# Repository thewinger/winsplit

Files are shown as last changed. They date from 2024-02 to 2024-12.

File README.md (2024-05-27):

# Winsplit

Inspired by the Boardrun Bizarre and Red herring. I wanted to be able to use a normal keyset, so no full ortho, but split.

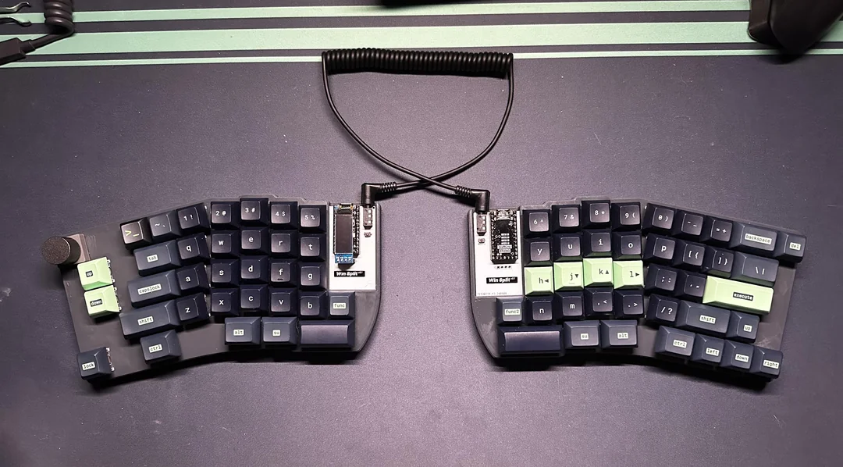
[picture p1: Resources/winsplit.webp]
Keyboard


## Disclaimer

This is my first designed keyboard from the grounds up.
I'm not responsible for any damage caused by using this keyboard or any production of this keyboard that doesn't work.

## Bill of materials

To be bought separately:

- 2x [RP2040 Pro Micro](https://es.aliexpress.com/item/1005006130019224.html).
- 70x pin headers
- 1x [Skyloong Rotary Encoder](https://es.aliexpress.com/item/1005005189266585.html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).
- 2x [TRRS Connector](https://es.aliexpress.com/item/33029465106.html).
- 2x [SMD Buttons](https://es.aliexpress.com/item/33013562004.html).
- 2x 128x32 [OLED panels](https://es.aliexpress.com/item/1005005973981064.html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).
- 73x [Kailh hotswap sockets](https://es.aliexpress.com/item/1005004290562374.html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).
- 73x [SK6812MINI-E leds](https://es.aliexpress.com/item/1005004908622116.html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).
- 4x 2u Stabilizers.
- 16x M2 6mm screws.

Diodes, capacitors, resistors and other small parts are to be soldered directly by JLCPCB. References in KiCad files.

## TODO

- [ ] **Rotate 180º right-side OLED connector.** Right now is not usable.
- [ ] **Rotary encoder.** As of now, it either works as a button when a normal switch is installed or as an encoder without button when the HS Skyloong encoder is installed.
- [ ] **Make screw holes in PCB 4mm instead of 2.2mm.** So they are passthrougth and bottom plate can be directly screwed to top plate, like lily58 or Corne keyboards.

## Notes

- Function keys (Right of B and left of N) are hard to reach.

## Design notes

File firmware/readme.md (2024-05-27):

# winsplit

winsplit

*A short description of the keyboard/project*

* Keyboard Maintainer: [thewinger](https://github.com/thewinger)
* Hardware Supported: *The PCBs, controllers supported*
* Hardware Availability: *Links to where you can find this hardware*

Make example for this keyboard (after setting up your build environment):

    make winsplit:default

Flashing example for this keyboard:

    make winsplit:default:flash

See the [build environment setup](https://docs.qmk.fm/#/getting_started_build_tools) and the [make instructions](https://docs.qmk.fm/#/getting_started_make_guide) for more information. Brand new to QMK? Start with our [Complete Newbs Guide](https://docs.qmk.fm/#/newbs).

## Bootloader

Enter the bootloader in 3 ways:

* **Bootmagic reset**: Hold down the key at (0,0) in the matrix (usually the top left key or Escape) and plug in the keyboard
* **Physical reset button**: Briefly press the button on the back of the PCB - some may have pads you must short instead
* **Keycode in layout**: Press the key mapped to `QK_BOOT` if it is available

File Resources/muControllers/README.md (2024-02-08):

# KiCAD Microcontroller symbols
Project boards for projects

(copyright and licensing info at bottom of this file)

This repository contains symbol libraries for use with KiCAD. These symbol
libraries are a selection of popular or notable microcontrollers. The goal is
to proveide the open source hardware community with tools to more easily create
new and interesting PCB projects without needing to redefine the wheel evey
single time.

## Supported boards
* Teensy
    * Teensy LC
    * Teensy 4.0
* RP2040
    * Raspberry Pi Pico
    * KB2040
* Others
    * Arduino Pro Micro
    * Adafruit Itsy Bitsy
    * CircuitBrains Deluxe
    * WeAct BlackPill

## Upcoming work
Provide footprints for all symbols

## Copyright and License
(c) Travis Rigg 2022, made available under the terms of the GNU LGPL 3.0



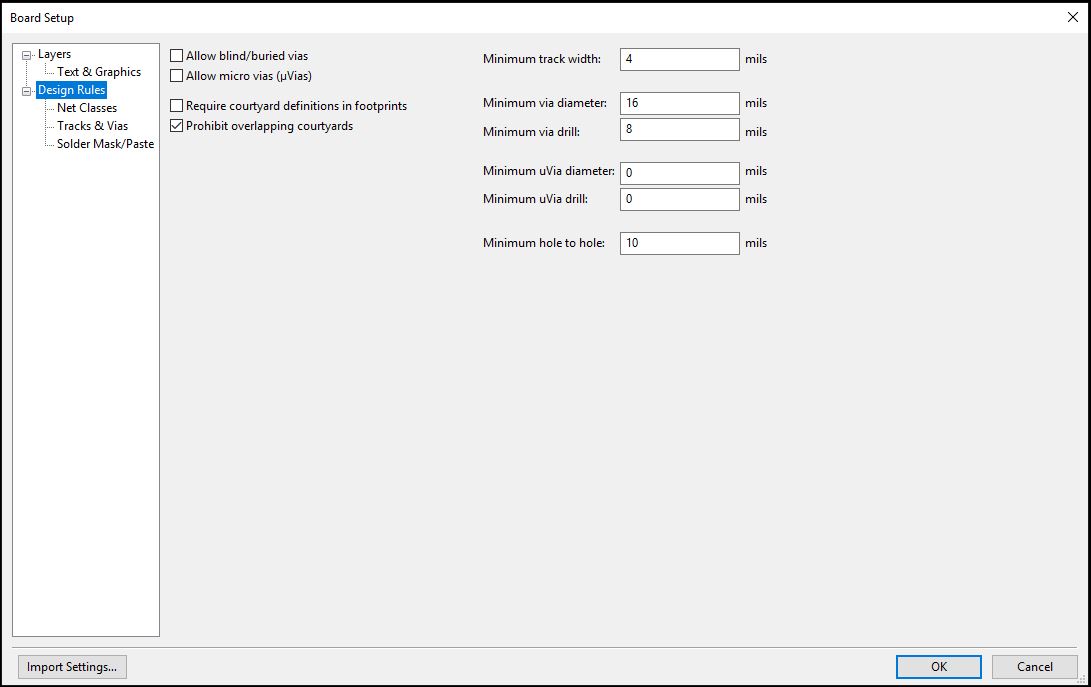
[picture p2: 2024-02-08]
Resources/kicad_templates-master/Sierra 10 layer Board/meta/Images/Design Rules.JPG

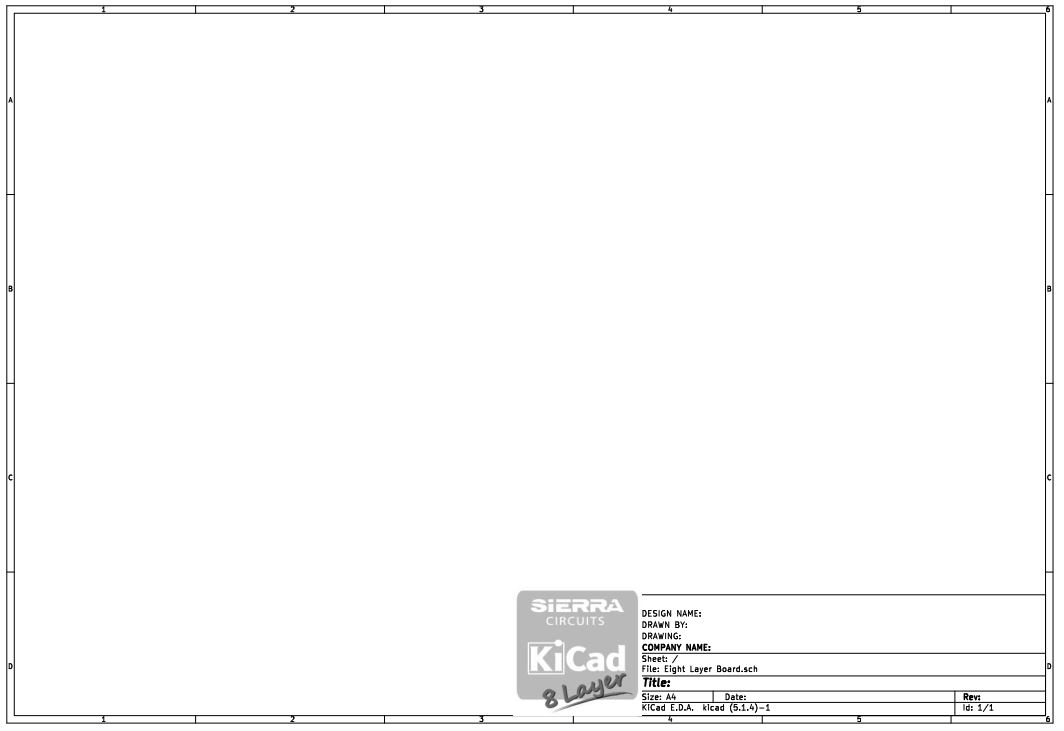
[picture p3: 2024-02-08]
Resources/kicad_templates-master/Sierra 8 layer Board/meta/Images/schematic.jpg

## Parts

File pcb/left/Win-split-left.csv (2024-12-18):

Id | Designator | Footprint | Quantity | Designation | Supplier and ref
1 | H1,H5,H6,H2,H8,H7,H3,H4 | HOLE_M2 | 8 | MountingHole_Pad
2 | S33,S23 | STAB_MX_P_2u | 2 | MX_stab
3 | J1 | PinHeader_1x04_P2.54mm_Vertical | 1 | Conn_01x04_Socket
4 | Reset1 | SW_SPST_B3U-1000P | 1 | Switch
5 | TRRS1 | TRRS_PJ-320A | 1 | TRRS
6 | U1 | RP2040_ProMicro_USBup | 1 | RP2040_ProMicro
7 | LED19,LED1,LED20,LED29,LED2,LED4,LED22,LED8,LED33,LED31,LED7,LED32,LED17,LED18,LED30,LED5,LED6,LED16,LED21,LED3 | LED_MX_6028R | 20 | MX_SK6812MINI-E
8 | D7,D19,D18,D20,D11,D15,D21,D29,D9,D12,D2,D23,D10,D5,D26,D31,D22,D34,D4,D3,D16,D8,D27,D13,D24,D6,D28,D1,D17,D14,D33,D30,D32,D25 | Diode_SOD-123 | 34 | Diode
9 | LED15,LED23,LED34,LED28,LED10,LED24,LED11,LED13,LED12,LED14,LED25,LED27,LED9,LED26 | LED_MX_6028R-ROT | 14 | MX_SK6812MINI-E
10 | MX33,MX8,MX6,MX14,MX11,MX5,MX17,MX27,MX3,MX20,MX10,MX28,MX13,MX22,MX21,MX15,MX29,MX26,MX12,MX25,MX1,MX19,MX4,MX2,MX24,MX34,MX23,MX7,MX18 | SW_MX_HS_CPG151101S11_1u | 29 | MX_SW_HS
11 | C5,C24,C28,C33,C34,C16,C1,C13,C29,C31,C32,C6,C30,C8,C14,C21,C4,C17,C20,C22,C3,C25,C9,C23,C11,C2,C12,C27,C15,C26,C10,C7,C19,C18,C100 | C_0402_1005Metric | 35 | 100nF
12 | MX32,MX30,MX31 | SW_MX_HS_CPG151101S11_1.25u | 3 | MX_SW_HS
13 | R2 | R_0805_2012Metric | 1 | 4.7K
14 | U3 | SOT-23-5 | 1 | 74AHCT1G125
15 | MX16 | SW_MX_HS_CPG151101S11_1.75u | 1 | MX_SW_HS
16 | Q1 | SOT-23 | 1 | Q_PMOS_GSD
17 | R1 | R_0805_2012Metric | 1 | 1K
18 | MX9 | SW_MX_HS_CPG151101S11_1.5u | 1 | MX_SW_HS

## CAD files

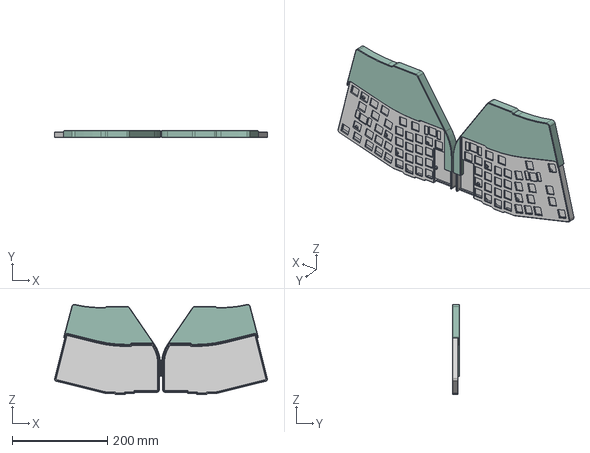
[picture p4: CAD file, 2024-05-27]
3D/Case winsplit.step
447.6 x 15.0 x 189.4 mm

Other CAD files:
3D/Case winsplit.3mf

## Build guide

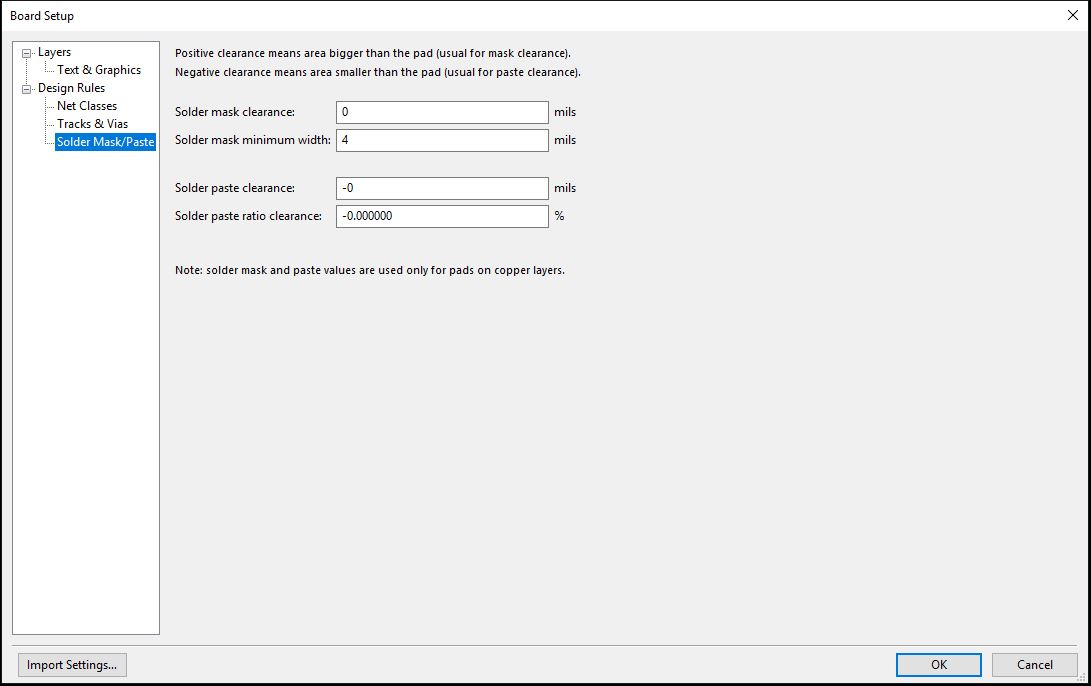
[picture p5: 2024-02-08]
Resources/kicad_templates-master/Sierra 2 layer Board/meta/Images/Solder Mask & Paste.JPG

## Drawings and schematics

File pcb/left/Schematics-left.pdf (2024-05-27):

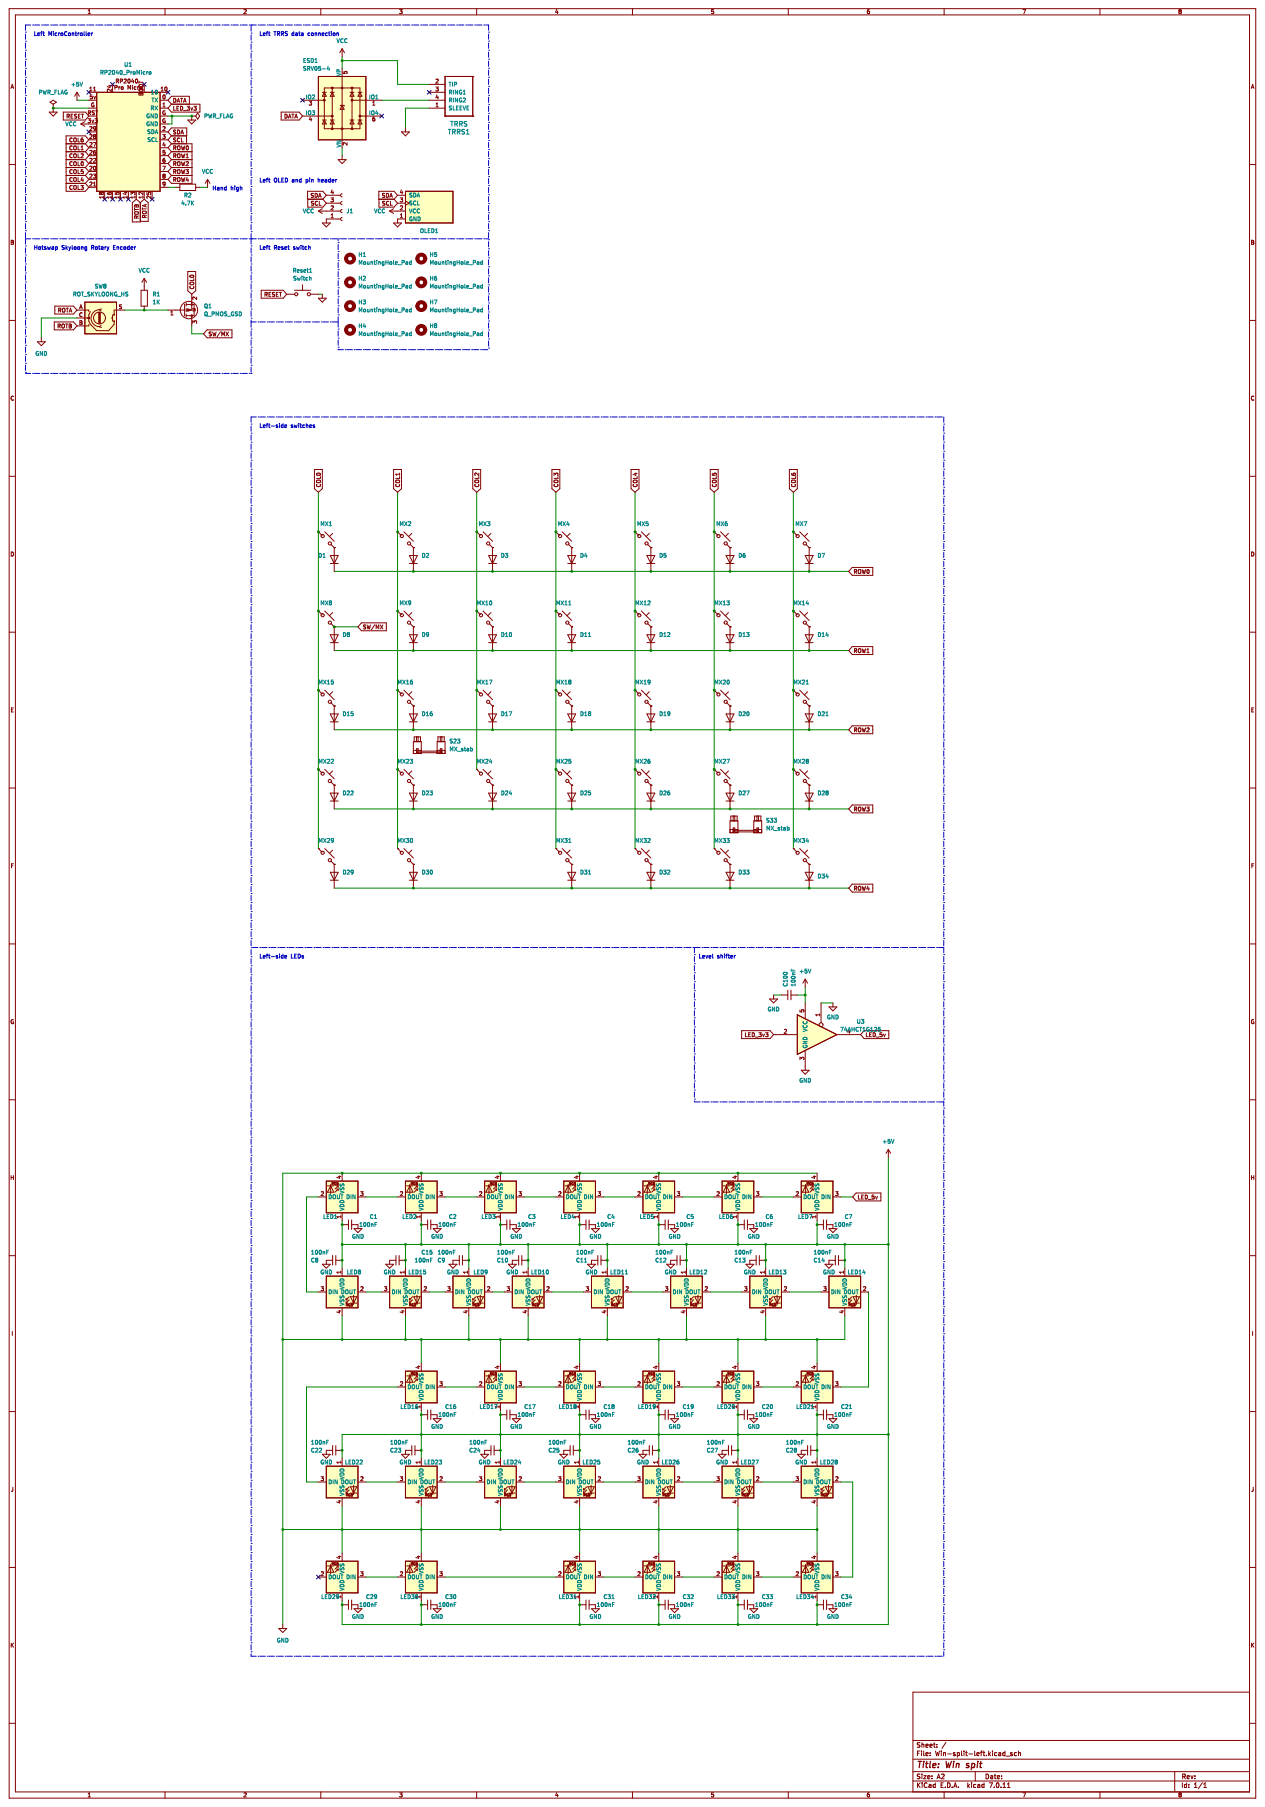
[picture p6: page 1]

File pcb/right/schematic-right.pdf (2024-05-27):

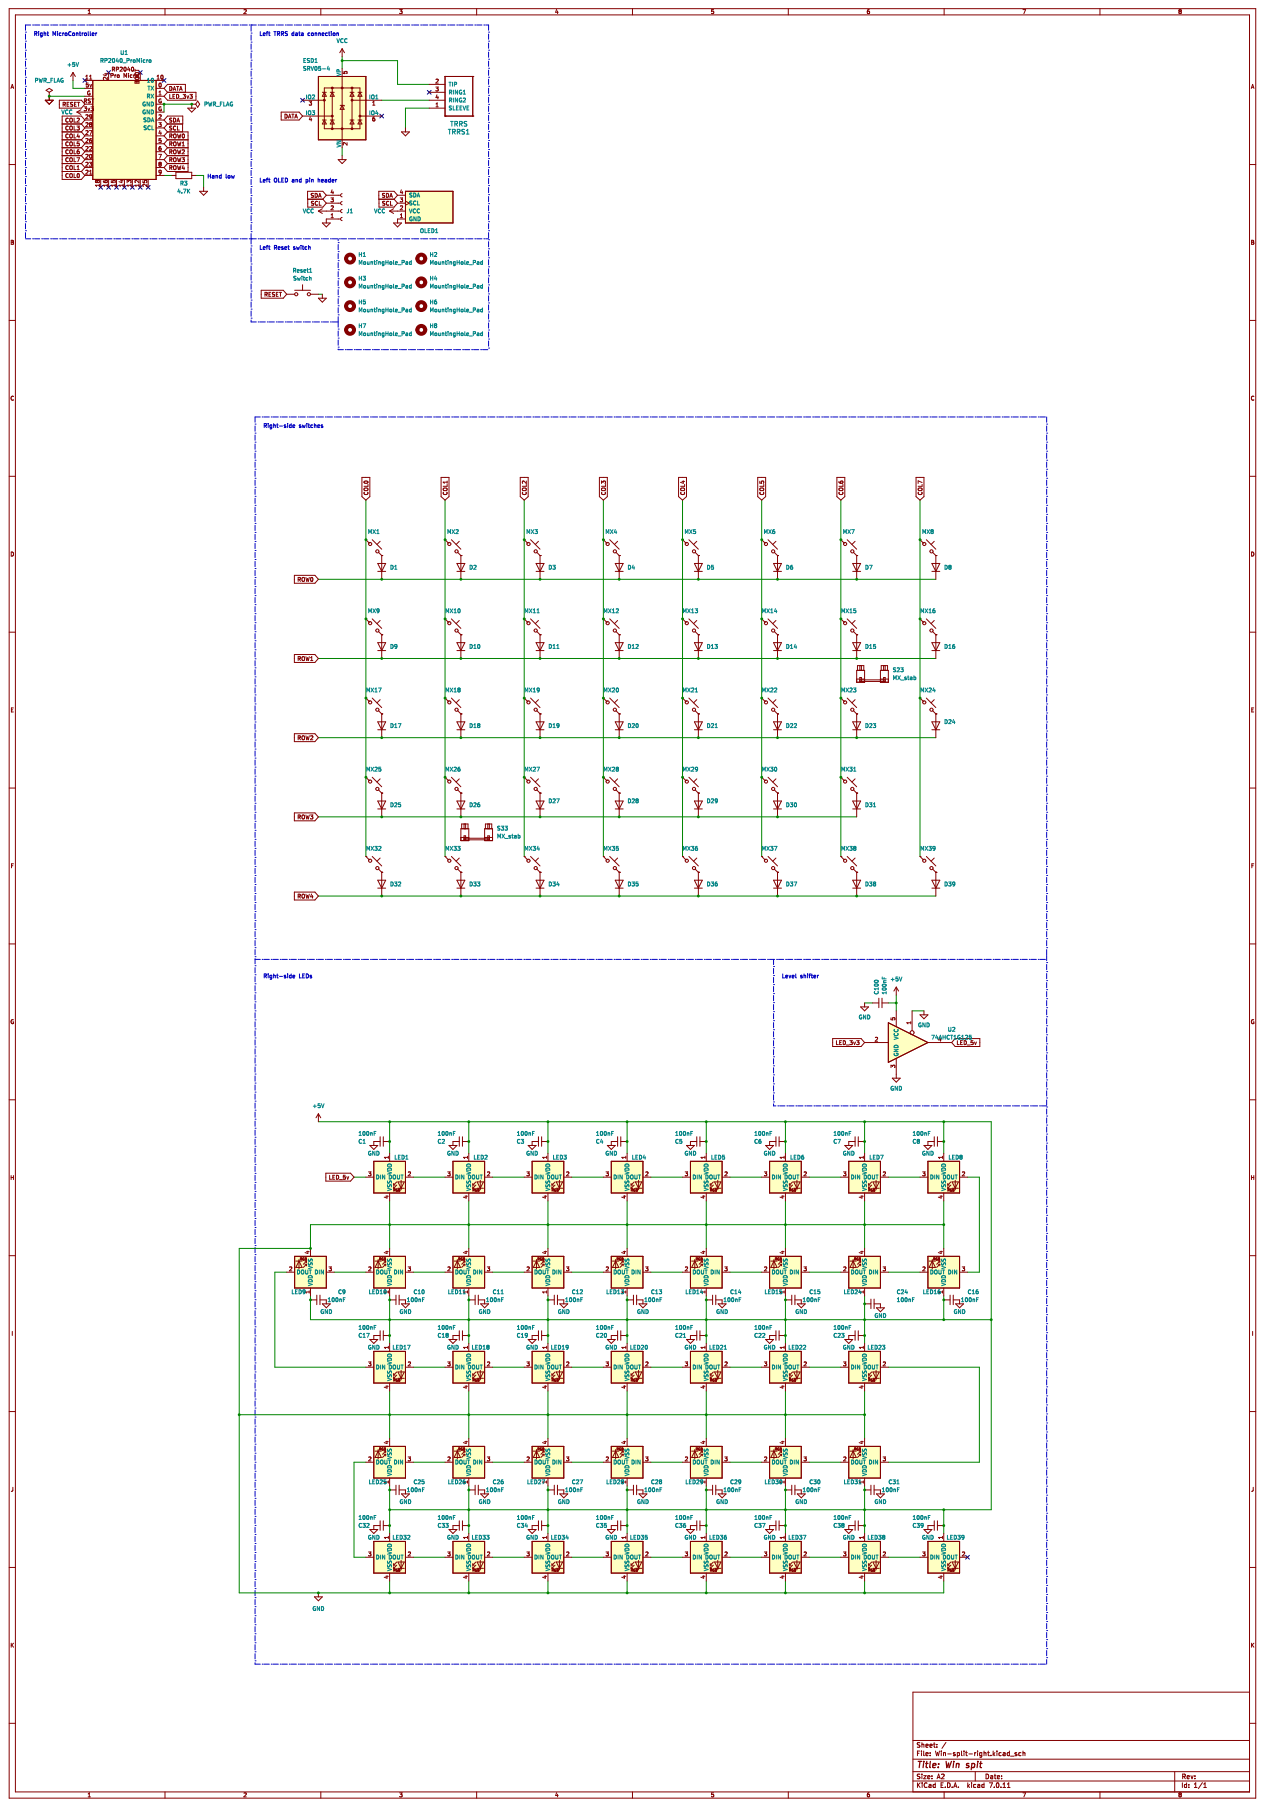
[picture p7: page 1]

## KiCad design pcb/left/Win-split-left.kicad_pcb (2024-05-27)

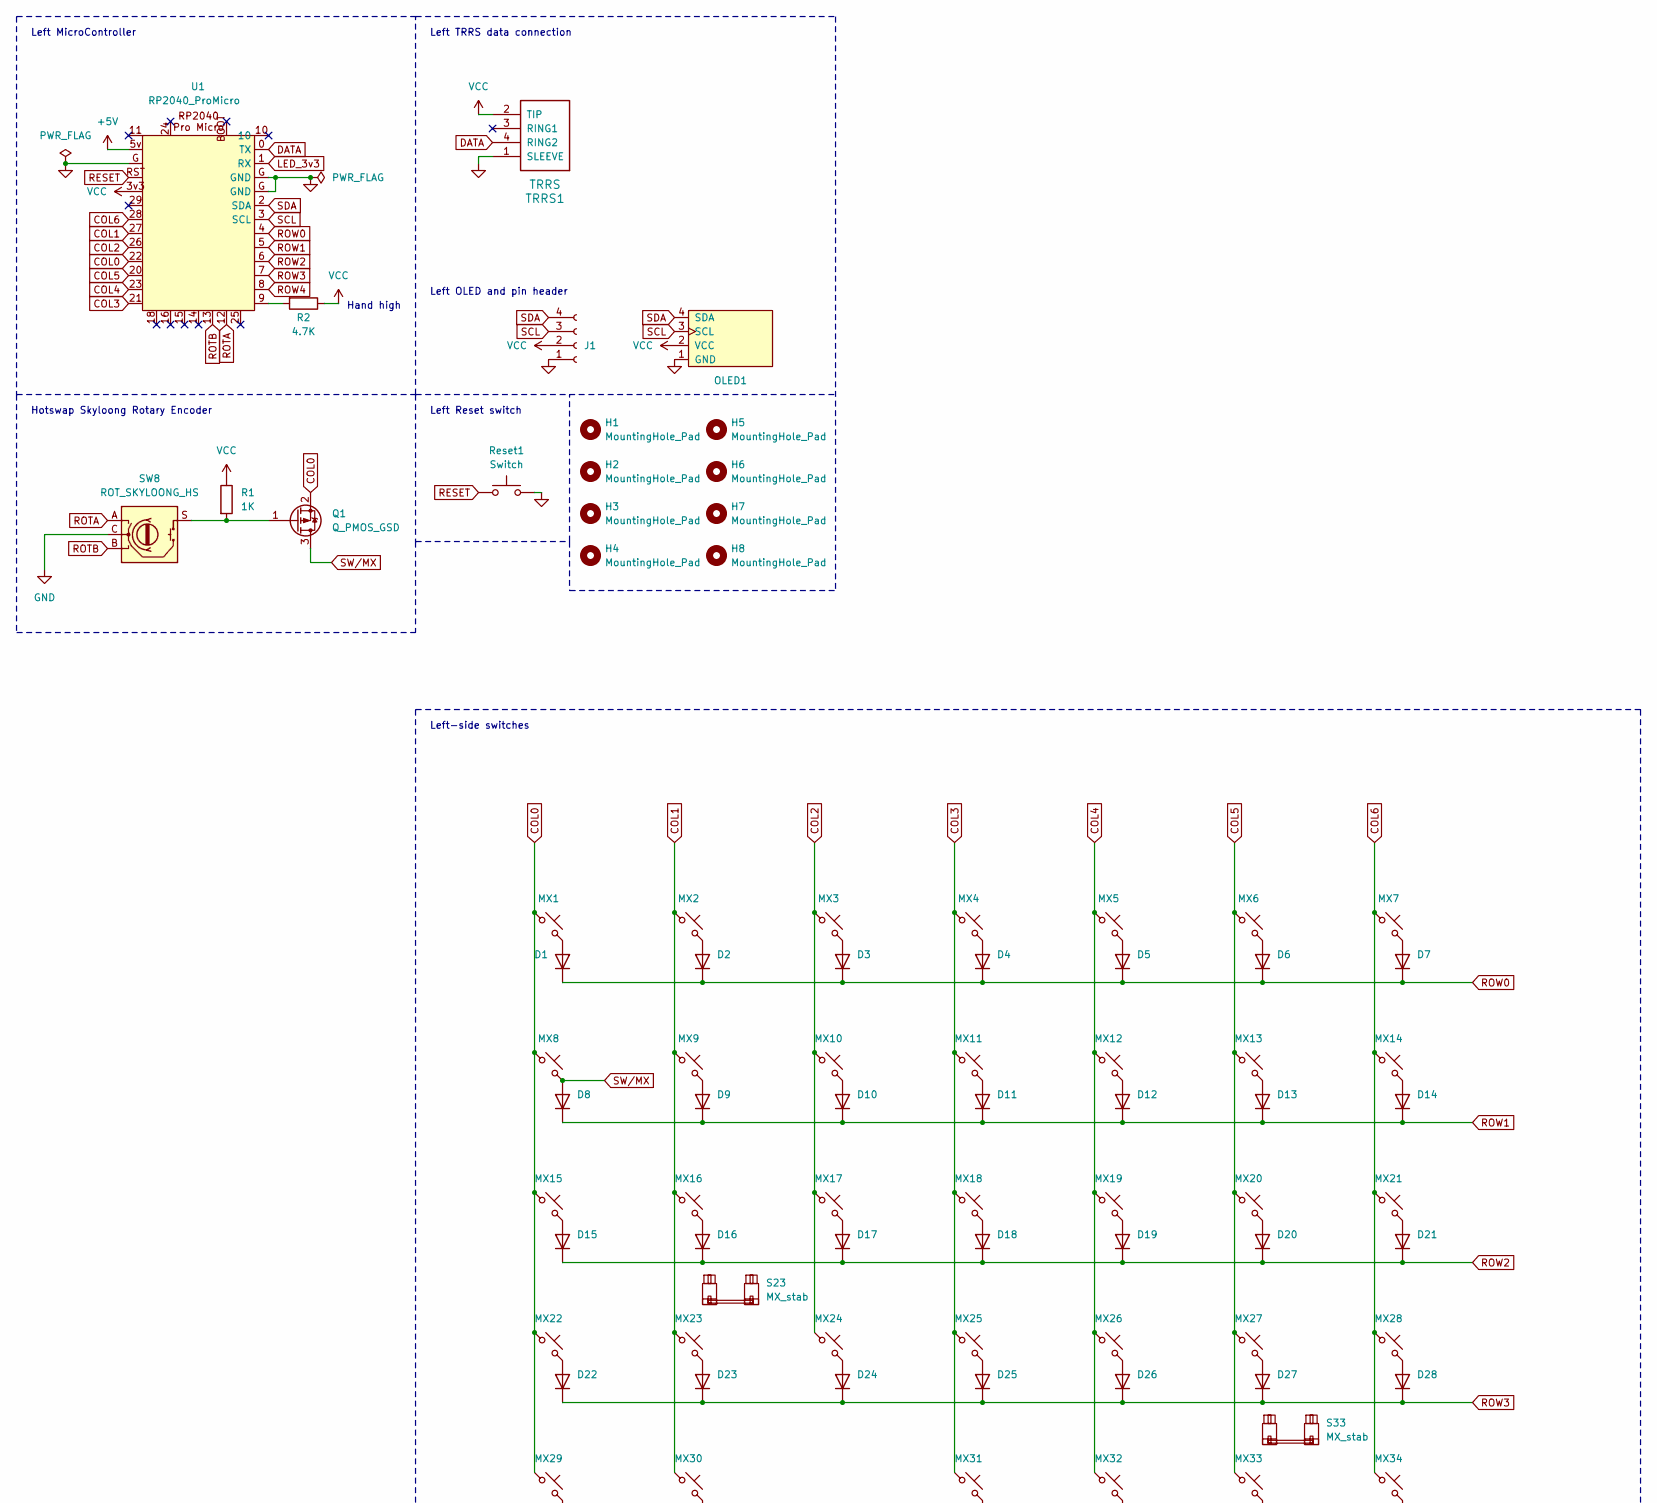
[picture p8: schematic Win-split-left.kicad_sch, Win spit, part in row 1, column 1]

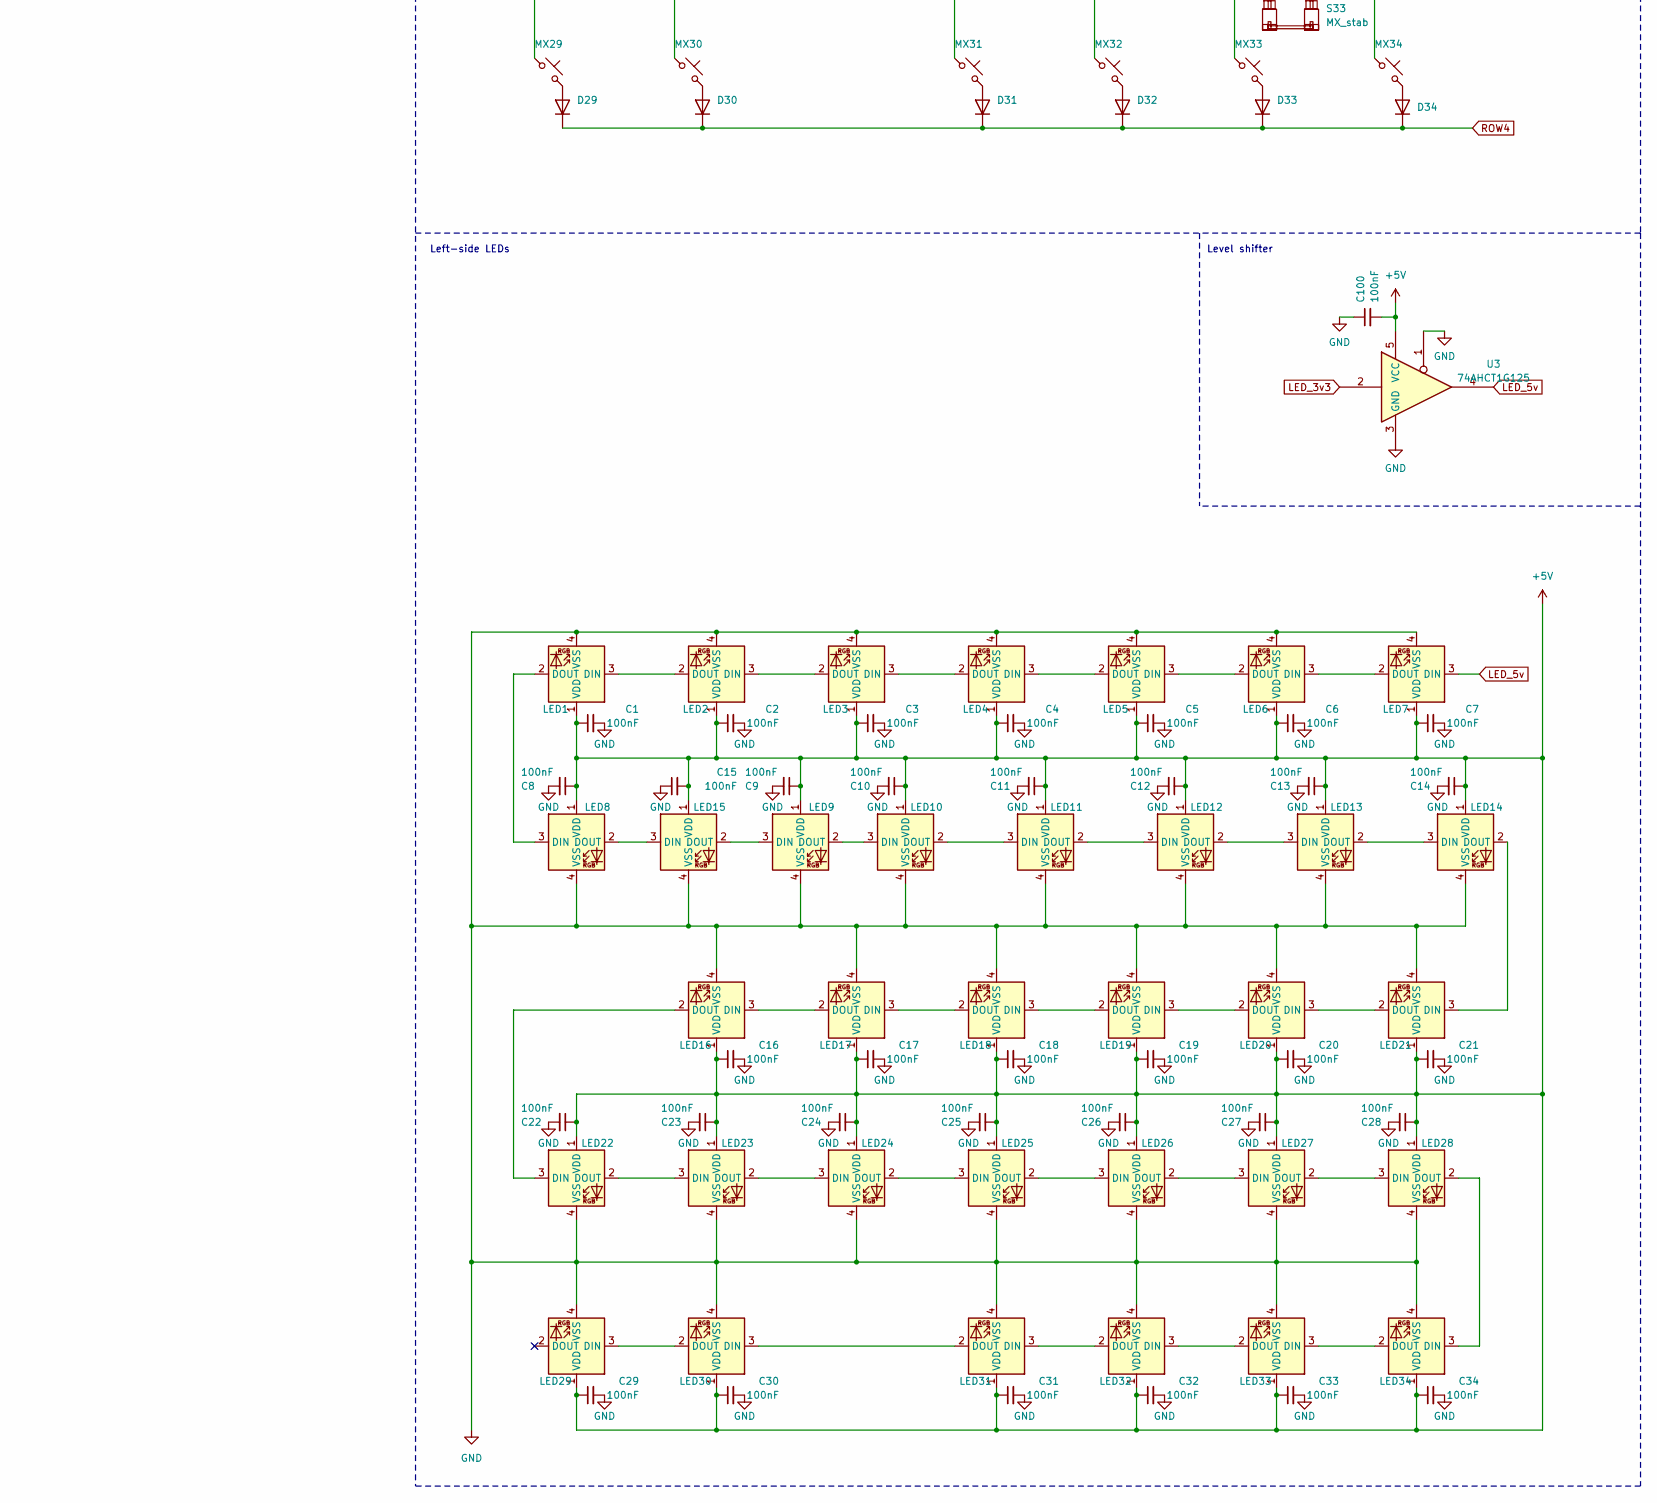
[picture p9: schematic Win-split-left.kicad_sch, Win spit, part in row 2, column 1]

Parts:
C1, C2, C3, C4, C5, C6, C7, C8, C9, C10, C11, C12, C13, C14, C15, C16, C17, C18, C19, C20, C21, C22, C23, C24, C25, C26, C27, C28, C29, C30, C31, C32, C33, C34, C100: 100nF; C_0402_1005Metric; LCSC C1525
D1, D2, D3, D4, D5, D6, D7, D8, D9, D10, D11, D12, D13, D14, D15, D16, D17, D18, D19, D20, D21, D22, D23, D24, D25, D26, D27, D28, D29, D30, D31, D32, D33, D34: Diode; Diode_SOD-123; LCSC C81598
H1, H2, H3, H4, H5, H6, H7, H8: MountingHole_Pad; HOLE_M2
J1: Conn_01x04_Socket; PinHeader_1x04_P2.54mm_Vertical
LED1, LED2, LED3, LED4, LED5, LED6, LED7, LED8, LED16, LED17, LED18, LED19, LED20, LED21, LED22, LED29, LED30, LED31, LED32, LED33: MX_SK6812MINI-E; LED_MX_6028R
LED9, LED10, LED11, LED12, LED13, LED14, LED15, LED23, LED24, LED25, LED26, LED27, LED28, LED34: MX_SK6812MINI-E; LED_MX_6028R-ROT
MX1, MX2, MX3, MX4, MX5, MX6, MX7, MX8, MX10, MX11, MX12, MX13, MX14, MX15, MX17, MX18, MX19, MX20, MX21, MX22, MX23, MX24, MX25, MX26, MX27, MX28, MX29, MX33, MX34: MX_SW_HS; SW_MX_HS_CPG151101S11_1u
MX9: MX_SW_HS; SW_MX_HS_CPG151101S11_1.5u
MX16: MX_SW_HS; SW_MX_HS_CPG151101S11_1.75u
MX30, MX31, MX32: MX_SW_HS; SW_MX_HS_CPG151101S11_1.25u
OLED1: OLED_128x32
Q1: Q_PMOS_GSD; SOT-23; LCSC C133325
R1: 1K; R_0805_2012Metric; LCSC C17513
R2: 4.7K; R_0805_2012Metric; LCSC C17673
Reset1: Switch; SW_SPST_B3U-1000P; LCSC C231329
S23, S33: MX_stab; STAB_MX_P_2u
SW8: ROT_SKYLOONG_HS; ROT_SKYLOONG_HS-Switch
TRRS1: TRRS; TRRS_PJ-320A
U1: RP2040_ProMicro; RP2040_ProMicro_USBup
U3: 74AHCT1G125; SOT-23-5; LCSC C7484

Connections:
+5V: C1.1, C2.1, C3.1, C4.1, C5.1, C6.1, C7.1, C8.1, C9.1, C10.1, C11.1, C12.1, C13.1, C14.1, C15.2, C16.1, C17.1, C18.1, C19.1, C20.1, C21.1, C22.1, C23.1, C24.1, C25.1, C26.1, C27.1, C28.1, C29.1, C30.1, C31.1, C32.1, C33.1, C34.1, C100.2, LED1.1 (VDD), LED2.1 (VDD), LED3.1 (VDD), LED4.1 (VDD), LED5.1 (VDD), LED6.1 (VDD), LED7.1 (VDD), LED8.1 (VDD), LED9.1 (VDD), LED10.1 (VDD), LED11.1 (VDD), LED12.1 (VDD), LED13.1 (VDD), LED14.1 (VDD), LED15.1 (VDD), LED16.1 (VDD), LED17.1 (VDD), LED18.1 (VDD), LED19.1 (VDD), LED20.1 (VDD), LED21.1 (VDD), LED22.1 (VDD), LED23.1 (VDD), LED24.1 (VDD), LED25.1 (VDD), LED26.1 (VDD), LED27.1 (VDD), LED28.1 (VDD), LED29.1 (VDD), LED30.1 (VDD), LED31.1 (VDD), LED32.1 (VDD), LED33.1 (VDD), LED34.1 (VDD), U1.5v, U3.5 (VCC)
COL0: MX1.1, MX8.1, MX15.1, MX22.1, MX29.1, Q1.2 (S), U1.22
COL1: MX2.1, MX9.1, MX16.1, MX23.1, MX30.1, U1.27
COL2: MX3.1, MX10.1, MX17.1, MX24.1, U1.26
COL3: MX4.1, MX11.1, MX18.1, MX25.1, MX31.1, U1.21
COL4: MX5.1, MX12.1, MX19.1, MX26.1, MX32.1, U1.23
COL5: MX6.1, MX13.1, MX20.1, MX27.1, MX33.1, U1.20
COL6: MX7.1, MX14.1, MX21.1, MX28.1, MX34.1, U1.28
DATA: TRRS1.4 (RING2), U1.0 (TX)
GND: C1.2, C2.2, C3.2, C4.2, C5.2, C6.2, C7.2, C8.2, C9.2, C10.2, C11.2, C12.2, C13.2, C14.2, C15.1, C16.2, C17.2, C18.2, C19.2, C20.2, C21.2, C22.2, C23.2, C24.2, C25.2, C26.2, C27.2, C28.2, C29.2, C30.2, C31.2, C32.2, C33.2, C34.2, C100.1, J1.1, LED1.4 (VSS), LED2.4 (VSS), LED3.4 (VSS), LED4.4 (VSS), LED5.4 (VSS), LED6.4 (VSS), LED7.4 (VSS), LED8.4 (VSS), LED9.4 (VSS), LED10.4 (VSS), LED11.4 (VSS), LED12.4 (VSS), LED13.4 (VSS), LED14.4 (VSS), LED15.4 (VSS), LED16.4 (VSS), LED17.4 (VSS), LED18.4 (VSS), LED19.4 (VSS), LED20.4 (VSS), LED21.4 (VSS), LED22.4 (VSS), LED23.4 (VSS), LED24.4 (VSS), LED25.4 (VSS), LED26.4 (VSS), LED27.4 (VSS), LED28.4 (VSS), LED29.4 (VSS), LED30.4 (VSS), LED31.4 (VSS), LED32.4 (VSS), LED33.4 (VSS), LED34.4 (VSS), OLED1.1 (GND), Reset1.2, SW8.C, TRRS1.1 (SLEEVE), U1.G (GND), U3.1, U3.3 (GND)
LED_3v3: U1.1 (RX), U3.2
LED_5v: LED7.3 (DIN), U3.4
unnamed: D1.2 (A), MX1.2
unnamed: D2.2 (A), MX2.2
unnamed: D3.2 (A), MX3.2
unnamed: D4.2 (A), MX4.2
unnamed: D5.2 (A), MX5.2
unnamed: D6.2 (A), MX6.2
unnamed: D7.2 (A), MX7.2
unnamed: D9.2 (A), MX9.2
unnamed: D10.2 (A), MX10.2
unnamed: D11.2 (A), MX11.2
unnamed: D12.2 (A), MX12.2
unnamed: D13.2 (A), MX13.2
unnamed: D14.2 (A), MX14.2
unnamed: D15.2 (A), MX15.2
unnamed: D16.2 (A), MX16.2
unnamed: D17.2 (A), MX17.2
unnamed: D18.2 (A), MX18.2
unnamed: D19.2 (A), MX19.2
unnamed: D20.2 (A), MX20.2
unnamed: D21.2 (A), MX21.2
unnamed: D22.2 (A), MX22.2
unnamed: D23.2 (A), MX23.2
unnamed: D24.2 (A), MX24.2
unnamed: D25.2 (A), MX25.2
unnamed: D26.2 (A), MX26.2
unnamed: D27.2 (A), MX27.2
unnamed: D28.2 (A), MX28.2
unnamed: D29.2 (A), MX29.2
unnamed: D30.2 (A), MX30.2
unnamed: D31.2 (A), MX31.2
unnamed: D32.2 (A), MX32.2
unnamed: D33.2 (A), MX33.2
unnamed: D34.2 (A), MX34.2
unnamed: LED1.3 (DIN), LED2.2 (DOUT)
unnamed: LED1.2 (DOUT), LED8.3 (DIN)
unnamed: LED2.3 (DIN), LED3.2 (DOUT)
unnamed: LED3.3 (DIN), LED4.2 (DOUT)
unnamed: LED4.3 (DIN), LED5.2 (DOUT)
unnamed: LED5.3 (DIN), LED6.2 (DOUT)
unnamed: LED6.3 (DIN), LED7.2 (DOUT)
unnamed: LED9.2 (DOUT), LED10.3 (DIN)
unnamed: LED10.2 (DOUT), LED11.3 (DIN)
unnamed: LED11.2 (DOUT), LED12.3 (DIN)
unnamed: LED12.2 (DOUT), LED13.3 (DIN)
unnamed: LED13.2 (DOUT), LED14.3 (DIN)
unnamed: LED14.2 (DOUT), LED21.3 (DIN)
unnamed: LED8.2 (DOUT), LED15.3 (DIN)
unnamed: LED9.3 (DIN), LED15.2 (DOUT)
unnamed: LED16.3 (DIN), LED17.2 (DOUT)
unnamed: LED16.2 (DOUT), LED22.3 (DIN)
unnamed: LED17.3 (DIN), LED18.2 (DOUT)
unnamed: LED18.3 (DIN), LED19.2 (DOUT)
unnamed: LED19.3 (DIN), LED20.2 (DOUT)
unnamed: LED20.3 (DIN), LED21.2 (DOUT)
unnamed: LED22.2 (DOUT), LED23.3 (DIN)
unnamed: LED23.2 (DOUT), LED24.3 (DIN)
unnamed: LED24.2 (DOUT), LED25.3 (DIN)
unnamed: LED25.2 (DOUT), LED26.3 (DIN)
unnamed: LED26.2 (DOUT), LED27.3 (DIN)
unnamed: LED27.2 (DOUT), LED28.3 (DIN)
unnamed: LED28.2 (DOUT), LED34.3 (DIN)
unnamed: LED29.3 (DIN), LED30.2 (DOUT)
unnamed: LED30.3 (DIN), LED31.2 (DOUT)
unnamed: LED31.3 (DIN), LED32.2 (DOUT)
unnamed: LED32.3 (DIN), LED33.2 (DOUT)
unnamed: LED33.3 (DIN), LED34.2 (DOUT)
unnamed: Q1.1 (G), R1.2, SW8.S
unnamed: R2.2, U1.9
RESET: Reset1.1, U1.RST
ROTA: SW8.A, U1.12
ROTB: SW8.B, U1.13
ROW0: D1.1 (K), D2.1 (K), D3.1 (K), D4.1 (K), D5.1 (K), D6.1 (K), D7.1 (K), U1.4
ROW1: D8.1 (K), D9.1 (K), D10.1 (K), D11.1 (K), D12.1 (K), D13.1 (K), D14.1 (K), U1.5
ROW2: D15.1 (K), D16.1 (K), D17.1 (K), D18.1 (K), D19.1 (K), D20.1 (K), D21.1 (K), U1.6
ROW3: D22.1 (K), D23.1 (K), D24.1 (K), D25.1 (K), D26.1 (K), D27.1 (K), D28.1 (K), U1.7
ROW4: D29.1 (K), D30.1 (K), D31.1 (K), D32.1 (K), D33.1 (K), D34.1 (K), U1.8
SCL: J1.3, OLED1.3 (SCL), U1.3 (SCL)
SDA: J1.4, OLED1.4 (SDA), U1.2 (SDA)
SW/MX: D8.2 (A), MX8.2, Q1.3 (D)
VCC: J1.2, OLED1.2 (VCC), R1.1, R2.1, TRRS1.2 (TIP), U1.3v3

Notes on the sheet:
Left-side switches
Left MicroController
Left Reset switch
Left OLED and pin header
Level shifter
Left-side LEDs
Hand high
Left TRRS data connection
Hotswap Skyloong Rotary Encoder

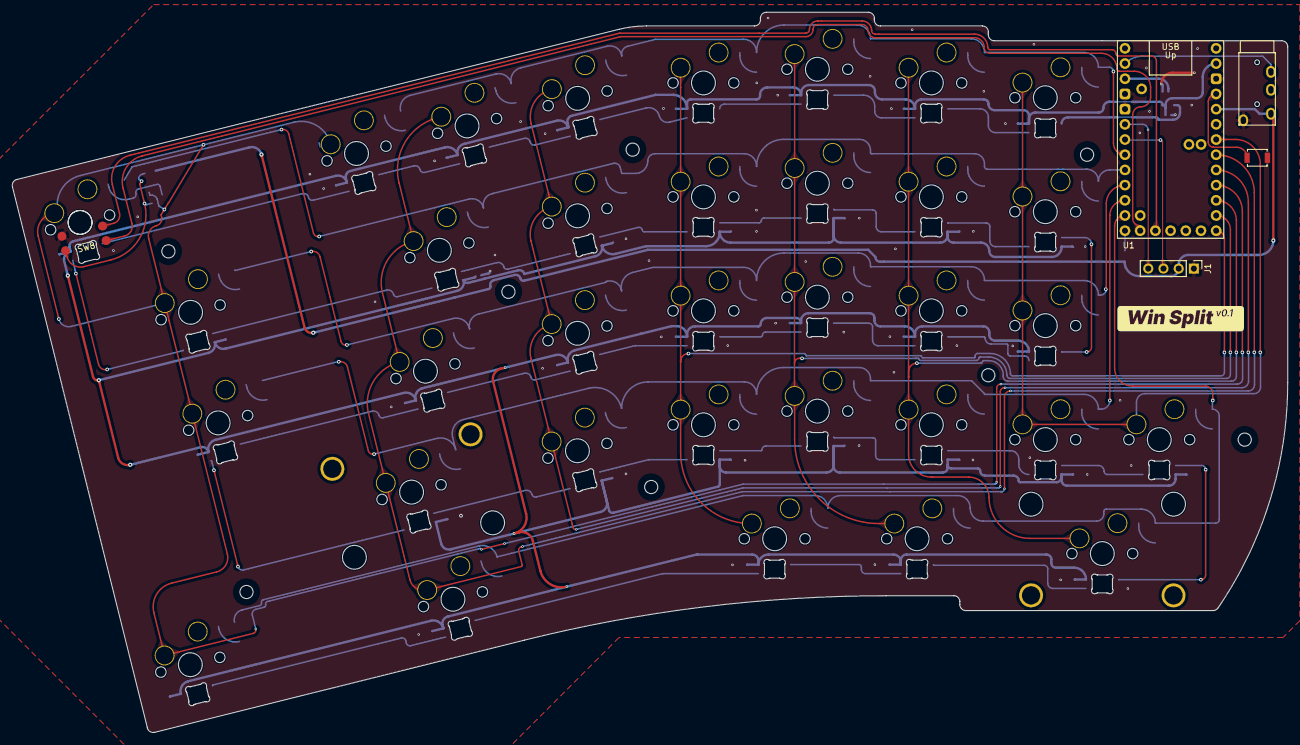
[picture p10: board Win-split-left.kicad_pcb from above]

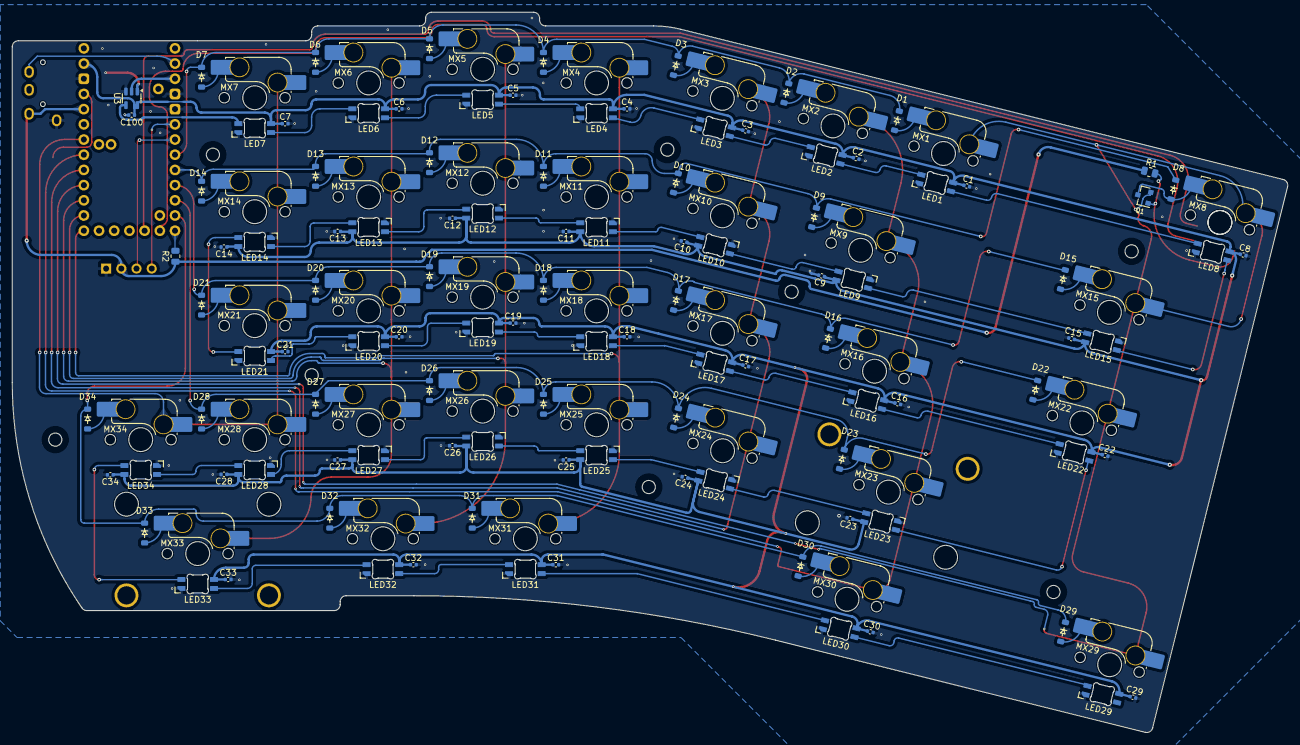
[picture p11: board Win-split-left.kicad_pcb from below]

Board: 2 copper layers, 213.2 x 120.4 mm, 156 parts (141 on the bottom side), 92 nets.

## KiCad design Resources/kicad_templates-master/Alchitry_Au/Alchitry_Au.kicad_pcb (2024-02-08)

Board: 2 copper layers, 8 parts (0 on the bottom side), 3 nets, no tracks yet.

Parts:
B1, B2, B3, B4: Alchitry_Shield; Alchitry_Conn
H1, H2, H3, H4: MountingHole; 2m2ThroughHole

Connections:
+3V3: B1.B7, B1.B13, B1.B19, B1.B25, B1.B26, B1.B32, B1.B38, B1.B44, B2.B7, B2.B13, B2.B19, B2.B25, B2.B26, B2.B32, B2.B38, B2.B44, B3.B7, B3.B13, B3.B19, B3.B25, B3.B26, B3.B32, B3.B38, B3.B44, B4.B7, B4.B13, B4.B19, B4.B25, B4.B26, B4.B32, B4.B38, B4.B44
+5V: B1.B1, B1.B50, B2.B1, B2.B50, B3.B1, B3.B50, B4.B50
GND: B1.B4, B1.B10, B1.B16, B1.B22, B1.B29, B1.B35, B1.B41, B1.B47, B2.B4, B2.B10, B2.B16, B2.B22, B2.B29, B2.B35, B2.B41, B2.B47, B3.B4, B3.B10, B3.B16, B3.B22, B3.B29, B3.B35, B3.B41, B3.B47, B4.B4, B4.B10, B4.B16, B4.B22, B4.B29, B4.B35, B4.B41, B4.B47

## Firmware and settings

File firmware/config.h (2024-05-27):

// Copyright 2024 thewinger (@thewinger)
// SPDX-License-Identifier: GPL-2.0-or-later

#pragma once


/*
 * Feature disable options
 *  These options are also useful to firmware size reduction.
 */

#define RP2040_BOOTLOADER_DOUBLE_TAP_RESET // Activates the double-tap behavior
#define RP2040_BOOTLOADER_DOUBLE_TAP_RESET_TIMEOUT 200U // Timeout window in ms in which the double tap can occur.
#define RP2040_BOOTLOADER_DOUBLE_TAP_RESET_LED GP17 // Specify a optional status led by GPIO number which blinks when entering the bootloader

#define I2C_DRIVER I2CD1
#define I2C1_SDA_PIN GP2
#define I2C1_SCL_PIN GP3

// #define DOUBLE_TAP_SHIFT_TURNS_ON_CAPS_WORD
#define CAPS_WORD_INVERT_ON_SHIFT

#define TAPPING_TERM 200
#define TAPPING_TERM_PER_KEY

/* disable debug print */
//#define NO_DEBUG
// #define SERIAL_USART_TX_PIN GP0     // The GPIO pin that is used split communication.
/* disable print */
//#define NO_PRINT

/* disable action features */
//#define NO_ACTION_LAYER
//#define NO_ACTION_TAPPING
//#define NO_ACTION_ONESHOT

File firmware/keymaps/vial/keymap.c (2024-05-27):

// Copyright 2023 QMK
// SPDX-License-Identifier: GPL-2.0-or-later

#include QMK_KEYBOARD_H

// enum layer_names {
//     BASE,
// };

enum custom_keycodes {
    B_NTIL = QK_KB_0,
    B_MUTE,
};

const uint16_t PROGMEM keymaps[][MATRIX_ROWS][MATRIX_COLS] = {

    //,-------,-------,-------,-------,-------,-------,-------,-------,               ,-------,-------,-------,-------,-------,-------,-------,-------,-------,
    //|       |       |       |       |       |       |       |       |               |       |       |       |       |       |       |       |       |       |
    //|-------+       --------+-------+-------+-------+-------+-------+               ,-------+-------+-------+-------+-------+-------+-------+-------+-------`
    //|       |               |       |       |       |       |       |               |       |       |       |       |       |       |       |
    //|-------+               +-------+-------+-------+-------+-------+-------,-------,-------+-------+-------+-------+-------+-------+-------+
    //|       |               |       |       |       |       |       |       |       |       |       |       |       |       |       |       |
    //|-------+               +-------+-------+-------+-------+-------+-------+-------+-------+-------+-------+-------+-------+-------+-------+
    //|       |               |       |       |       |       |               |               |       |       |       |       |       |       |
    //`-------`               `-------`       `-------`-------`---------------`---------------`-------`-------`-------`-------`-------`-------

    [0] = LAYOUT(
        KC_MPLY,CW_TOGG,KC_GRV,          KC_1, KC_2, KC_3, KC_4, KC_5,               KC_6, KC_7, KC_8, KC_9, KC_0, KC_MINS, KC_EQL, KC_BSPC, KC_DEL,
        KC_PGUP,        KC_TAB,          KC_Q, KC_W, KC_E, KC_R, KC_T,               KC_Y, KC_U, KC_I, KC_O, KC_P, KC_LBRC, KC_RBRC, KC_BSLS,
        KC_MPLY,        CTL_T(KC_ESC),   KC_A, KC_S, KC_D, KC_F, KC_G,               KC_H, KC_J, KC_K, KC_L, KC_SCLN, KC_QUOT, KC_ENT,
                        SC_LSPO,         KC_Z, KC_X, KC_C, KC_V, KC_B, MO(1), MO(2), KC_N, KC_M, KC_COMM, KC_DOT, KC_SLSH, SC_RSPC, KC_UP,
        B_MUTE,         KC_LCTL,         KC_LALT, KC_LGUI,  LT(1, KC_SPC),  LT(2, KC_SPC), KC_RGUI, KC_RALT,      KC_RCTL, KC_LEFT, KC_DOWN, KC_RGHT),

    [1] = LAYOUT(_______, _______, _______, KC_F1, KC_F2, KC_F3, KC_F4, KC_F5, KC_F6, KC_F7, KC_F8, KC_F9, KC_F10, KC_F11, KC_F12, _______, _______,
                 KC_HOME, _______, _______, KC_UP, _______, _______, _______, _______, KC_P7, KC_P8, KC_P9, _______, _______, _______, _______,
                 KC_END, _______, KC_LEFT, KC_DOWN, KC_RIGHT, _______, _______, _______, KC_P4, KC_P5, KC_P6, _______, _______, _______,
                 _______, _______, _______, _______, _______, _______, _______, _______, B_NTIL, KC_P1, KC_P2, KC_P3, KC_P0, _______, _______,
                 _______, _______, _______, _______, _______, LT(3, KC_BSPC), _______, _______, _______, _______, _______, _______),

    [2] = LAYOUT(_______, _______, _______, _______, _______, _______, _______, _______, _______, _______, _______, _______, _______, _______, _______, _______, _______,
                 _______, _______, _______, _______, _______, _______, _______, _______, _______, _______, _______, _______, _______, _______, _______,
                 _______, _______, _______, _______, _______, _______, _______, KC_LEFT, KC_DOWN, KC_UP, KC_RIGHT, _______, _______, _______,
                 _______, _______, _______, _______, _______, _______, _______, _______, B_NTIL, _______, _______, _______, _______, _______, _______,
                 _______, _______, _______, _______, _______, _______, _______, _______, _______, _______, _______, _______),

    [3] = LAYOUT(_______, _______, _______, _______, _______, _______, _______, _______, _______, _______, _______, _______, _______, _______, _______, _______, _______,
                 _______, _______, _______, _______, _______, _______, _______, _______, _______, _______, _______, _______, _______, _______, QK_BOOT,
                 _______, _______, _______, _______, _______, _______, _______, _______, _______, _______, _______, _______, _______, _______,
                 _______, _______, _______, _______, _______, _______, _______, _______, _______, _______, _______, _______, _______, _______, _______,
                 _______, _______, _______, _______, _______, _______, _______, _______, _______, _______, _______, _______),
};

#if defined(ENCODER_MAP_ENABLE)
const uint16_t PROGMEM encoder_map[][NUM_ENCODERS][2] = {
    [0] = {ENCODER_CCW_CW(KC_VOLD, KC_VOLU)},
    [1] = {ENCODER_CCW_CW(KC_VOLD, KC_VOLU)},
    [2] = {ENCODER_CCW_CW(KC_VOLD, KC_VOLU)},
    [3] = {ENCODER_CCW_CW(KC_VOLD, KC_VOLU)},
};
#endif

/* bool get_retro_tapping(uint16_t keycode, keyrecord_t *record) {
    switch (keycode) {
        case LT(2, KC_SPC):
            return true;
        default:
            return false;
    }
} */
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

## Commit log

2024-02-08 adds resources
    [AISLER-2Layer.kicad_pcb, AISLER-2Layer.sch, AISLER-4Layer.kicad_pcb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]
2024-02-25 pre-del button
    [Win-split-before-led_swap.kicad_sch, Win-split-bottom-and-top.kicad_pcb, Win-split.kicad_pcb]
2024-03-01 separated in 2 pcbs
    [Win-split-before-led_swap.kicad_sch, Win-split-bottom-and-top.kicad_pcb, Win-split-left.kicad_pcb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]
2024-03-08 kicad 7
    [Case left.step, Win-split-left-User_Eco2.dxf, Win-split-left.kicad_pcb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]
2024-03-12 before rounding tracks in left side
    [Win-split-left.kicad_pcb, Win-split-left.kicad_sch, Win-split-right.kicad_sch]
2024-03-13 prerouting right side
    [Win-split-left.kicad_pcb, Win-split-left.kicad_sch, Win-split-right.kicad_pcb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]
2024-05-27 vial firmware and 3D cases
    [Case left.step, Case winsplit.3mf, Case winsplit.step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]
2024-05-27 adds bill of materials to readme
